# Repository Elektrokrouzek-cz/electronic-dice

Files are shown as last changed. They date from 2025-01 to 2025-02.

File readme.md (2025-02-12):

# Electronic dice
This is the construction of electronic dice for RedNetCon technological conference
workshop. It is based on NE555 timer and 4017 logical circuit. All components are 
in THT packages.

PCB is 2-layer and was designed using KiCad 8. Fabrication output for JLCPCB is in gerber folder.

Happy soldering!

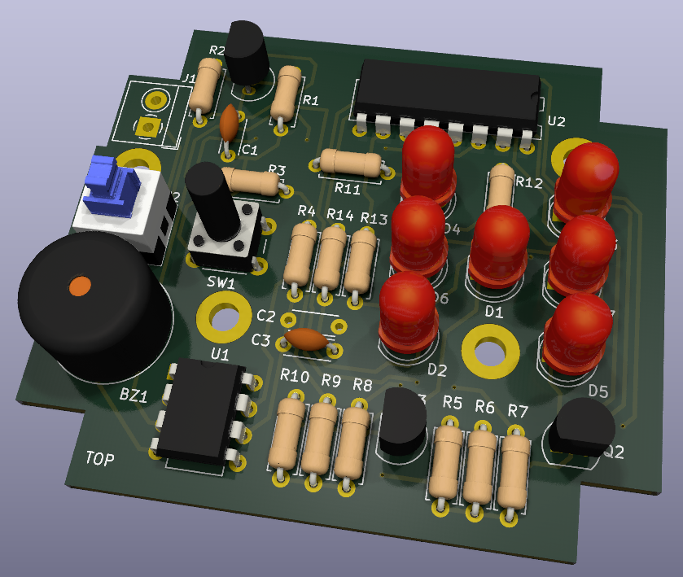
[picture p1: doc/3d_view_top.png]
3D view

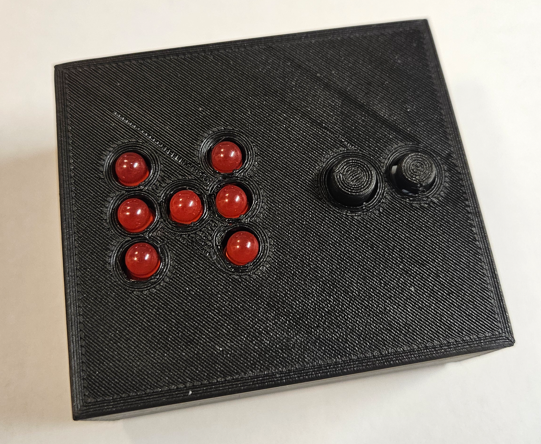
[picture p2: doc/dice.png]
Dice


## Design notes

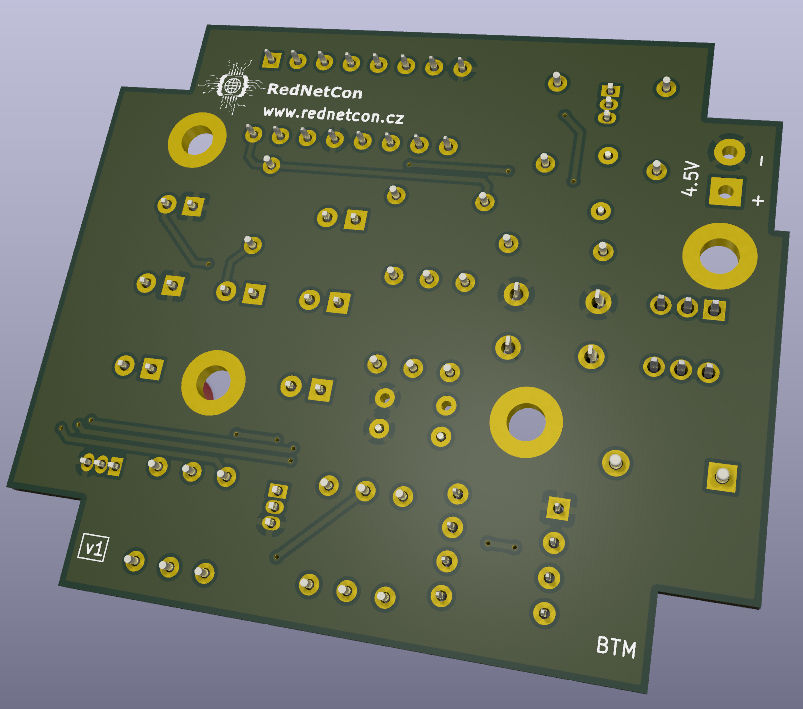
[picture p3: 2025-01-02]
doc/3d_view_btm.png

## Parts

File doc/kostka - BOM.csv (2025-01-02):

Reference | Value | Datasheet | Footprint | Qty | DNP
BZ1 | Buzzer | ~ | Buzzer_Beeper:Buzzer_12x9.5RM7.6 | 1
C1,C3 | 1uF | ~ | Capacitor_THT:C_Disc_D4.3mm_W1.9mm_P5.00mm | 2
C2 | 1uF | ~ | Capacitor_THT:C_Disc_D4.3mm_W1.9mm_P5.00mm | 1 | DNP
D1,D2,D3,D4,D5,D6,D7 | 5mm, R | ~ | LED_THT:LED_D5.0mm | 7
J1 | Screw_Terminal_01x02 | ~ | TerminalBlock_4Ucon:TerminalBlock_4Ucon_1x02_P3.50mm_Horizontal | 1
Q1 | BC556 | https://www.onsemi.com/pub/Collateral/BC556BTA-D.pdf | Package_TO_SOT_THT:TO-92_Inline | 1
Q2,Q3 | BC546 | https://www.onsemi.com/pub/Collateral/BC550-D.pdf | Package_TO_SOT_THT:TO-92_Inline | 2
R1,R2 | 1M | ~ | Resistor_THT:R_Axial_DIN0207_L6.3mm_D2.5mm_P7.62mm_Horizontal | 2
R3,R4,R5,R6,R7,R8,R9,R10 | 10k | ~ | Resistor_THT:R_Axial_DIN0207_L6.3mm_D2.5mm_P7.62mm_Horizontal | 8
R11,R13,R14 | 220R | ~ | Resistor_THT:R_Axial_DIN0207_L6.3mm_D2.5mm_P7.62mm_Horizontal | 3
R12 | 1k | ~ | Resistor_THT:R_Axial_DIN0207_L6.3mm_D2.5mm_P7.62mm_Horizontal | 1
SW1 | Push 6x6, H13mm | ~ | Button_Switch_THT:SW_PUSH_6mm_H13mm | 1
SW2 | DPDT 7x7mm, Turbo | ~ | Button_Switch_THT_Hap:SW_DPDT_7x7_Turbo | 1
U1 | NE555P | http://www.ti.com/lit/ds/symlink/ne555.pdf | Package_DIP:DIP-8_W7.62mm | 1
U2 | 4017 | http://www.intersil.com/content/dam/Intersil/documents/cd40/cd4017bms-22bms.pdf | Package_DIP:DIP-16_W7.62mm | 1

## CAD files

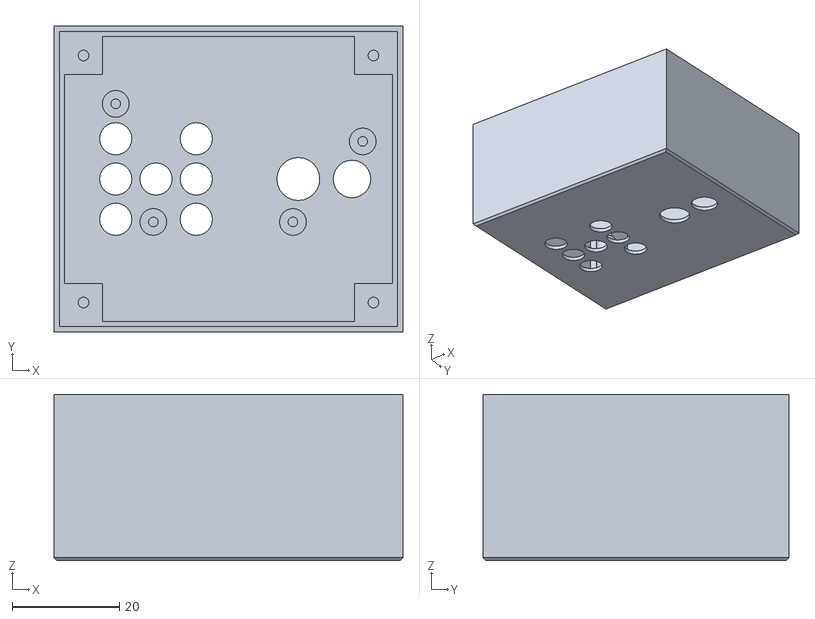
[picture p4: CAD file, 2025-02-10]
3d/dice_top.stl
65.0 x 57.0 x 31.0

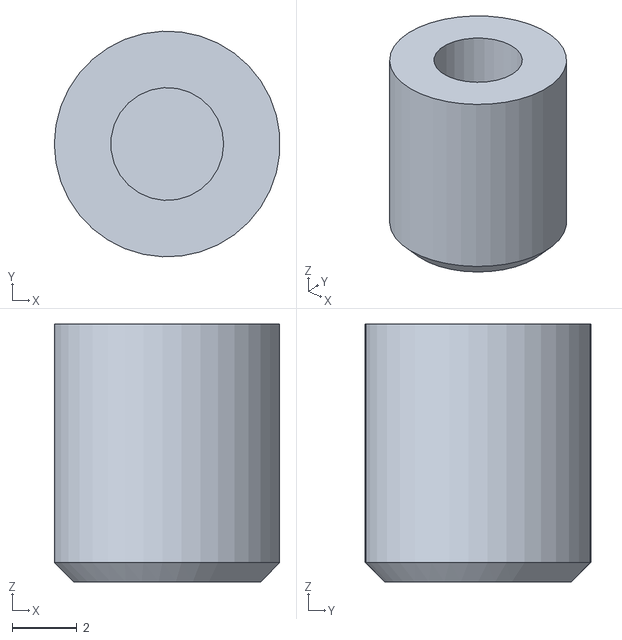
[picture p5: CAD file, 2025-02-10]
3d/dice_button_1.stl
6.99 x 6.99 x 8.00

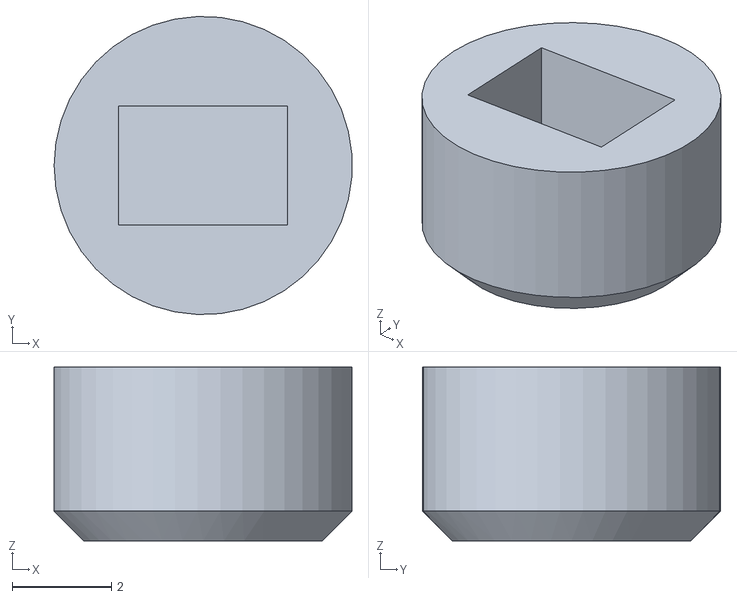
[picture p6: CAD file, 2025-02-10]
3d/dice_button_2.stl
5.99 x 6.00 x 3.50

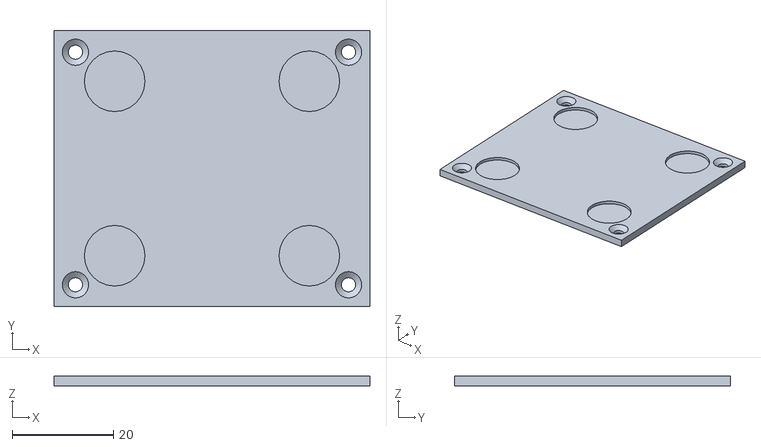
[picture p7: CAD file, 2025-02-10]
3d/dice_bottom.stl
62.5 x 54.5 x 2.00

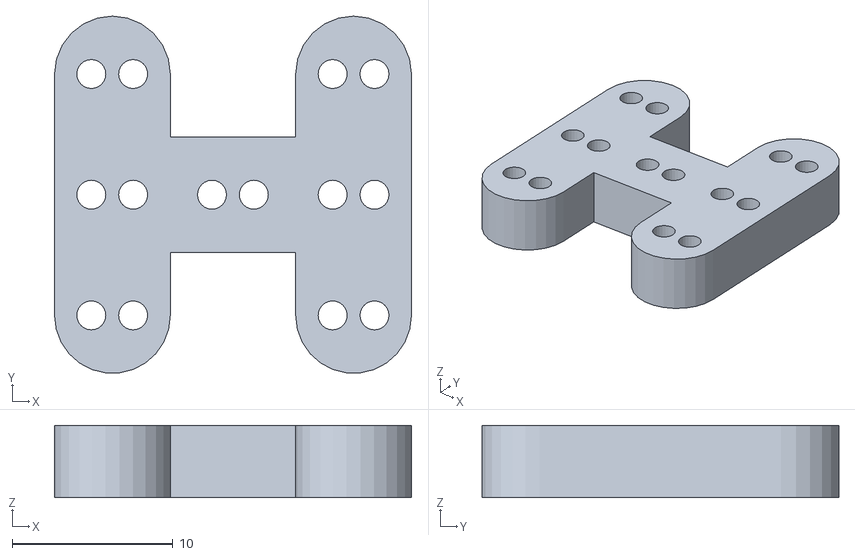
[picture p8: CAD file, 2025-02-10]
3d/dice_led_spacer.stl
22.2 x 22.2 x 4.50

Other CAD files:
3d/dice.f3d

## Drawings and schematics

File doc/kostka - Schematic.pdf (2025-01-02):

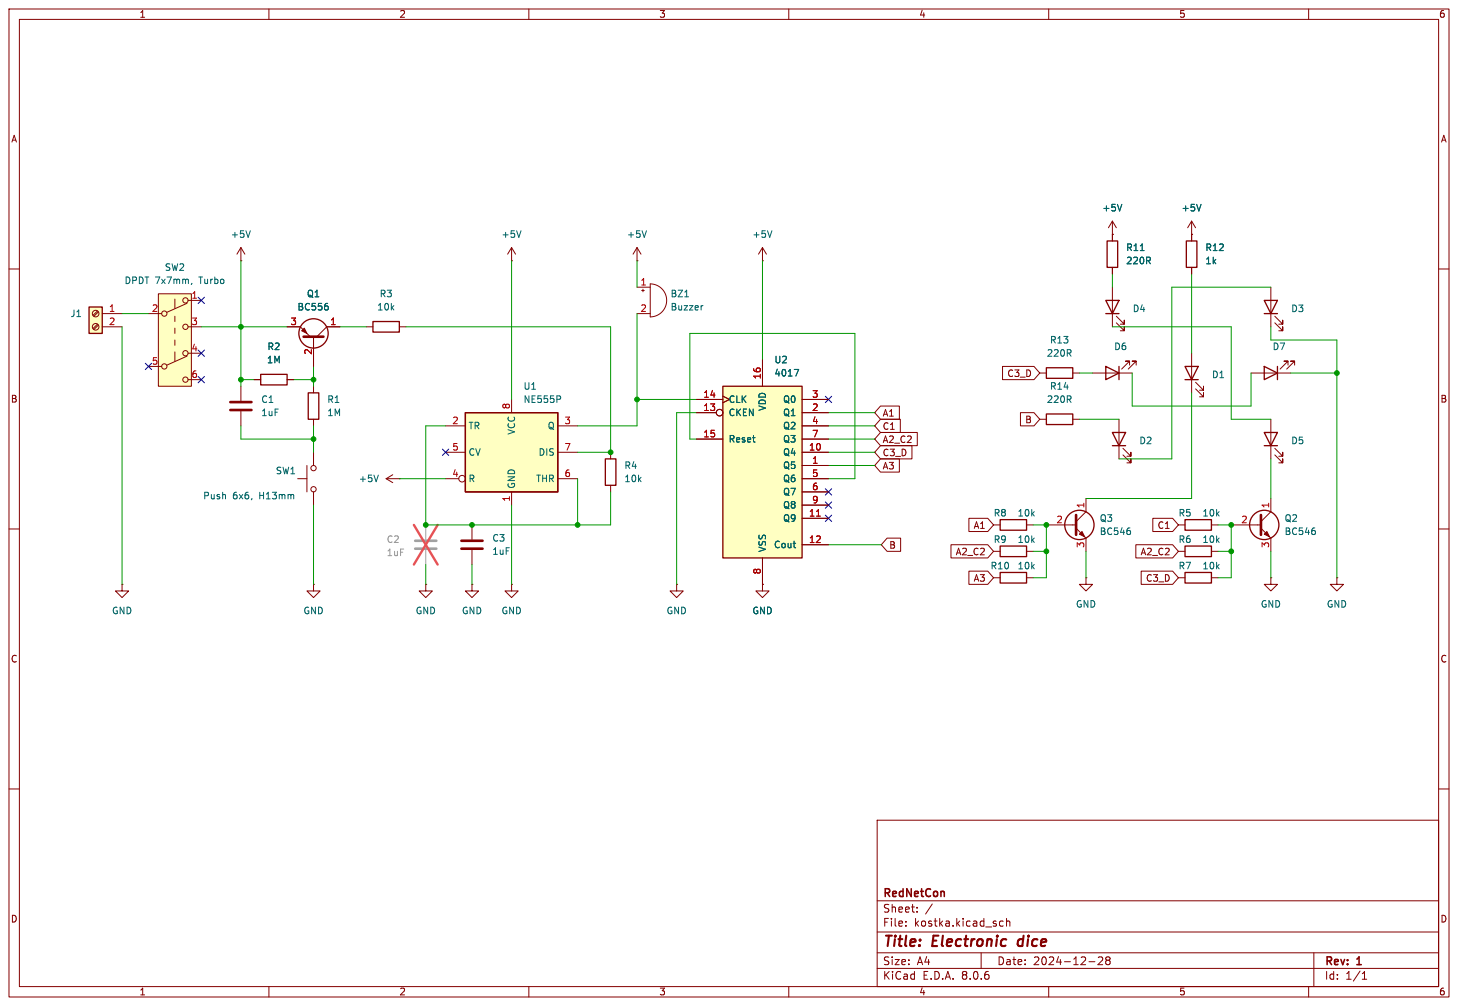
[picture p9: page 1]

File: kostka.kicad_sch Sheet: / RedNetCon

Id: 1/1 Title: Electronic dice

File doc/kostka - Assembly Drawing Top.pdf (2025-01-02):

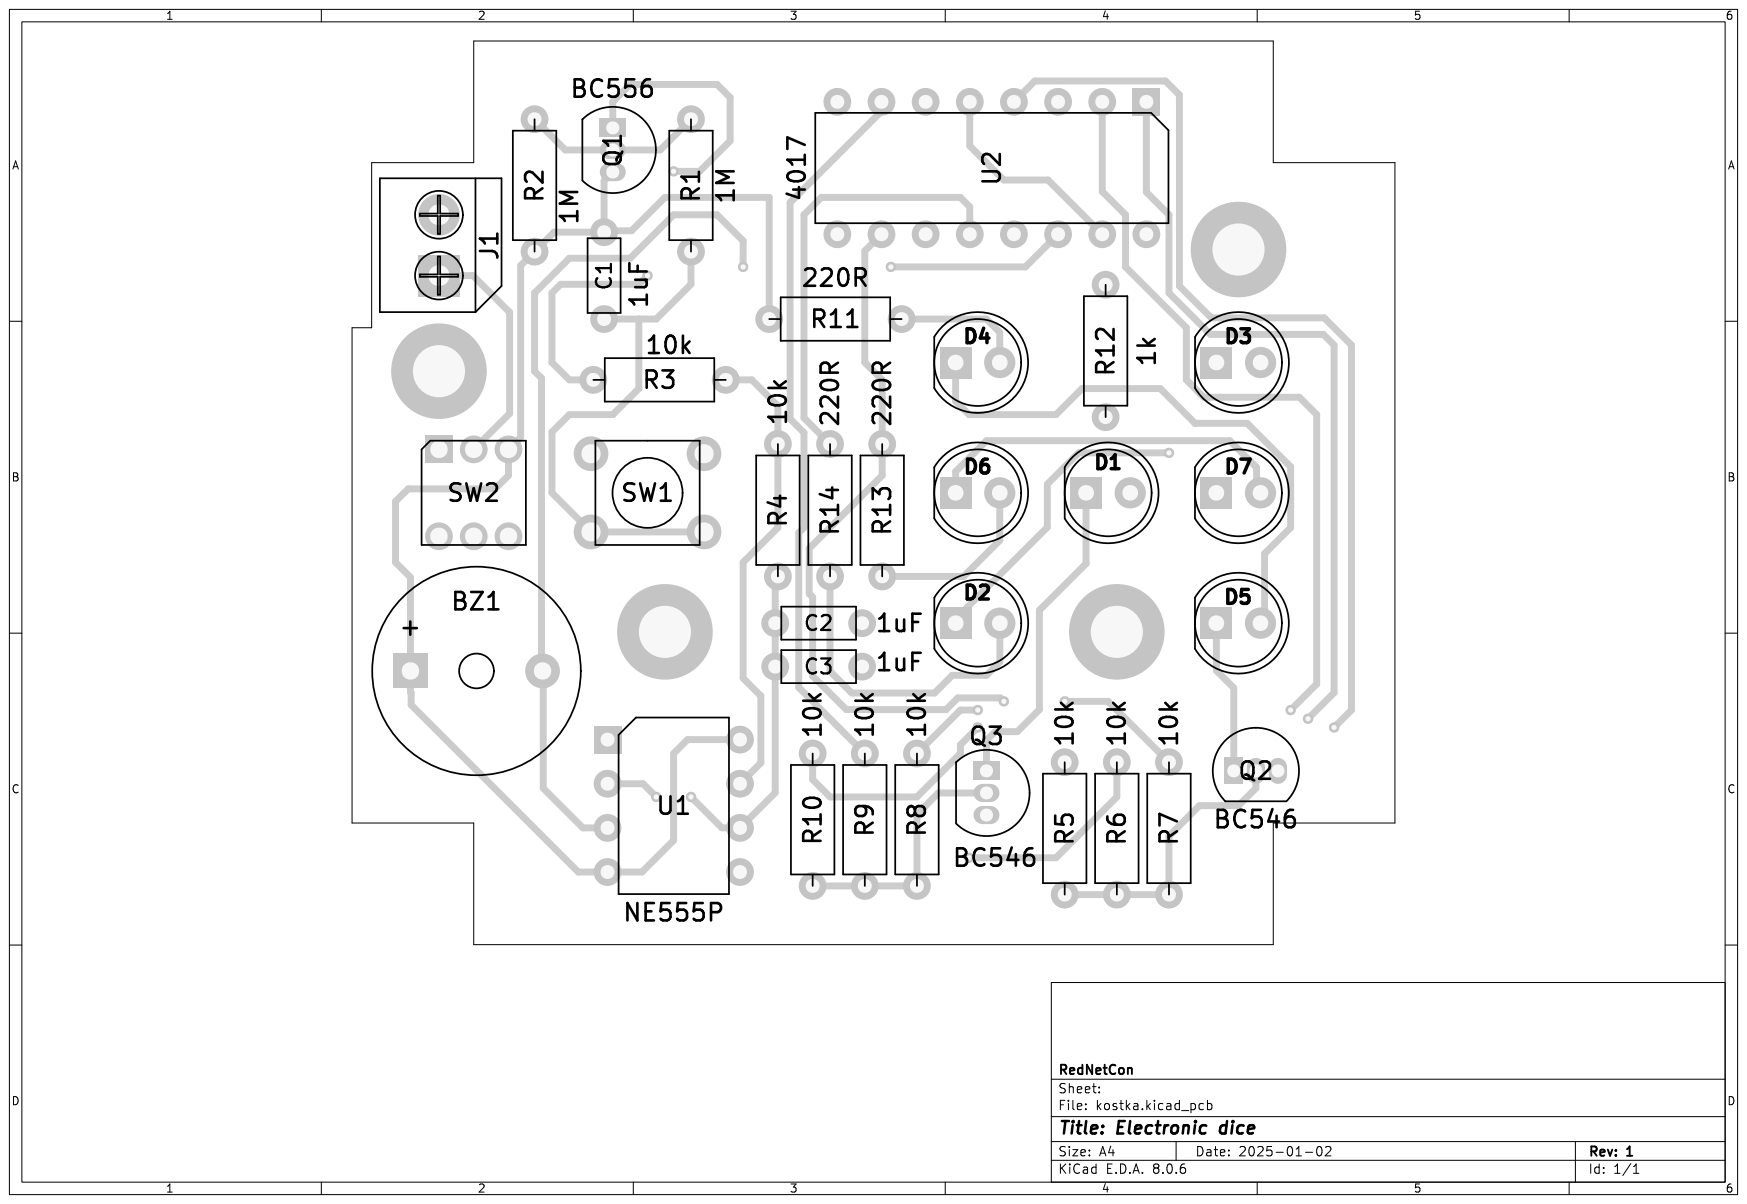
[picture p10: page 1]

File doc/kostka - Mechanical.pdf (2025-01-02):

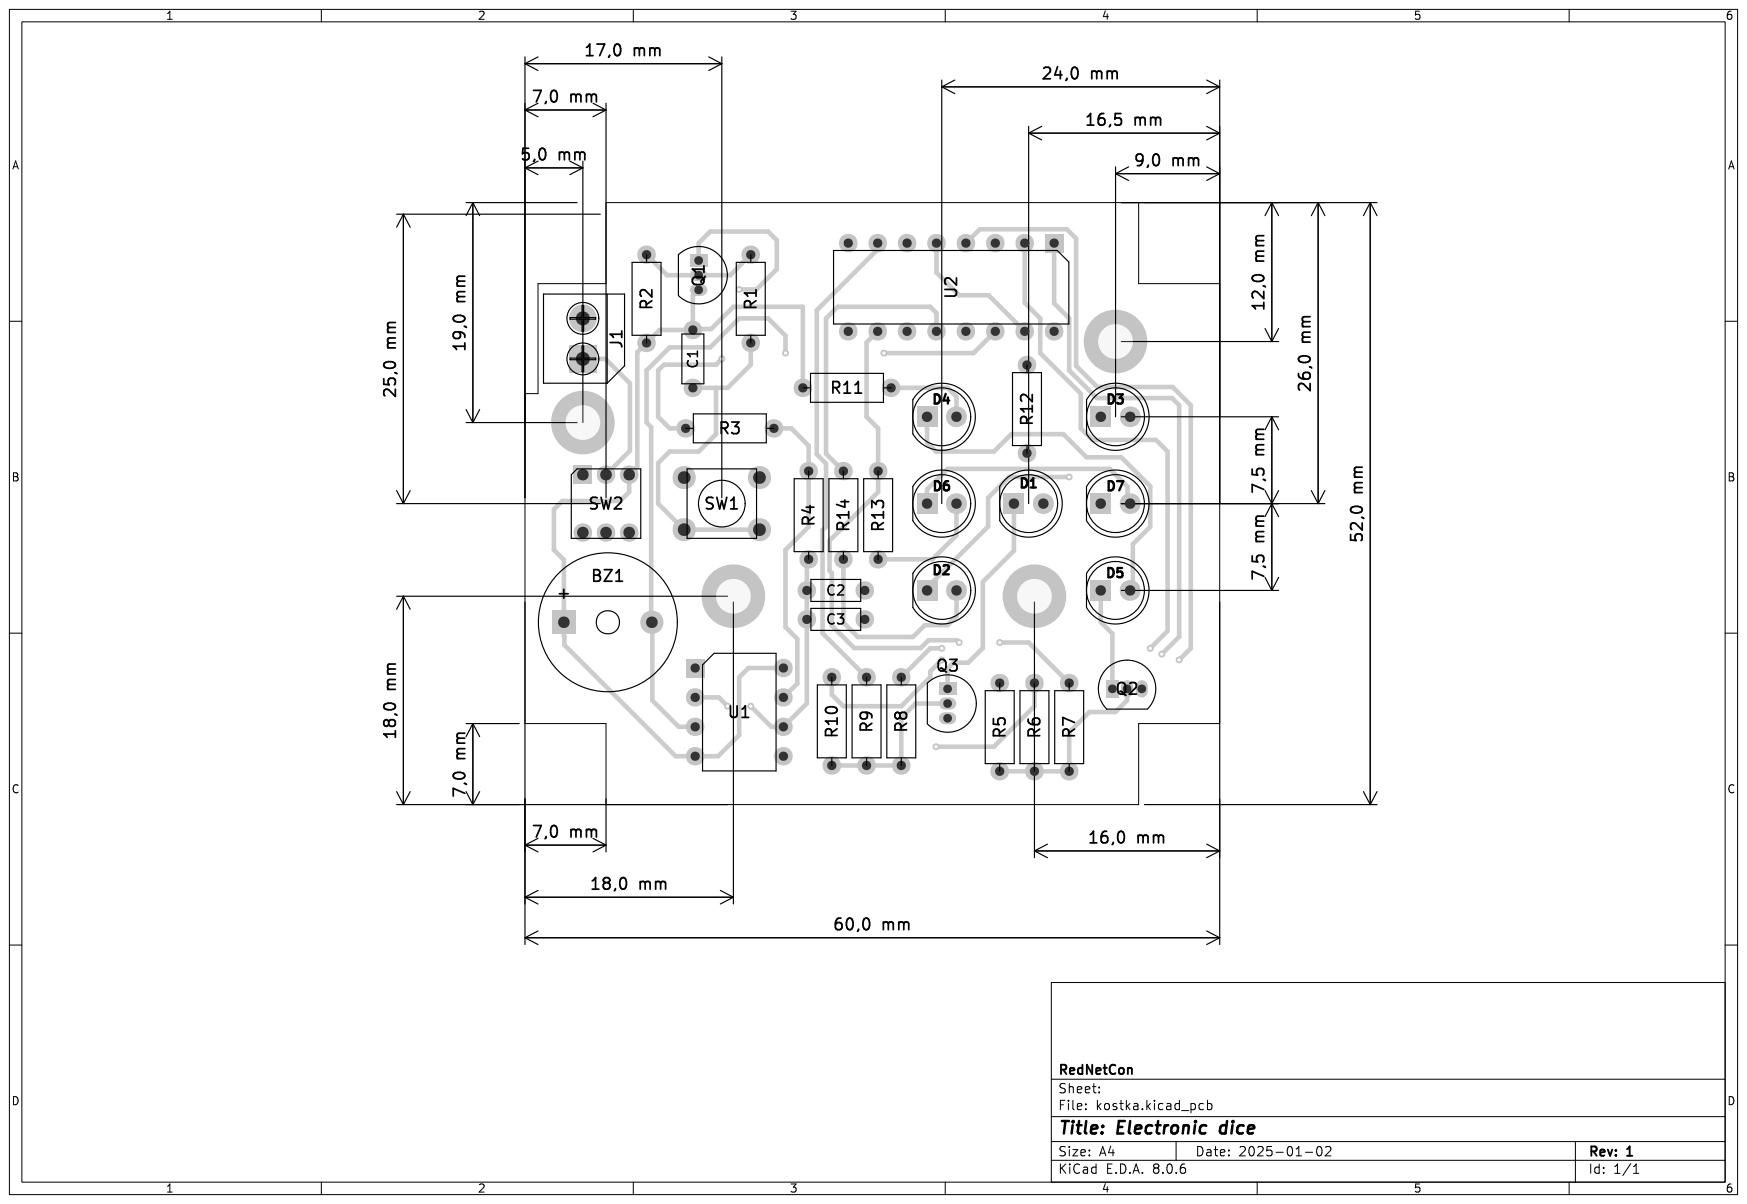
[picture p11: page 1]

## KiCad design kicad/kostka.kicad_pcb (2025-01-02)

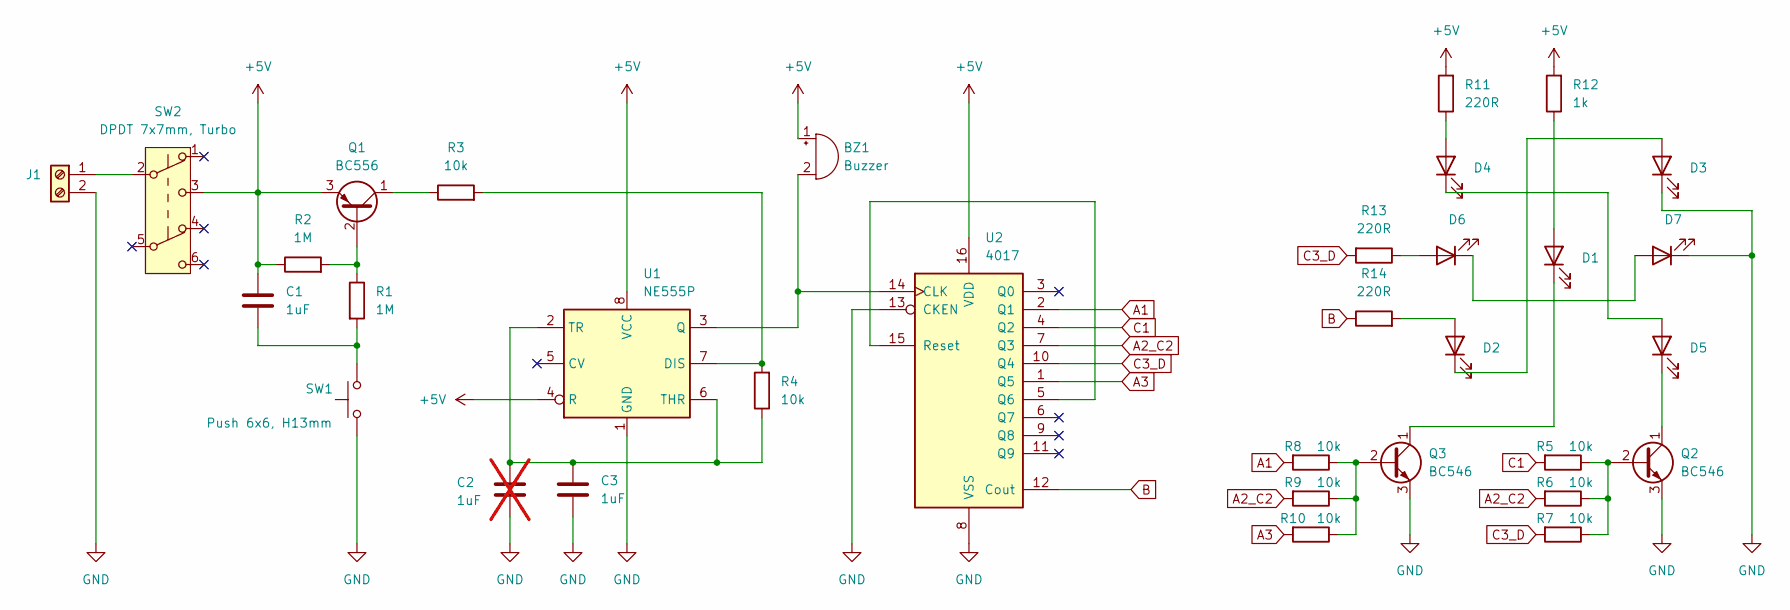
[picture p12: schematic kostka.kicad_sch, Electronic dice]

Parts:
BZ1: Buzzer; Buzzer_12x9.5RM7.6
C1, C3: 1uF; C_Disc_D4.3mm_W1.9mm_P5.00mm
C2: 1uF; C_Disc_D4.3mm_W1.9mm_P5.00mm; not fitted
D1, D2, D3, D4, D5, D6, D7: 5mm, R; LED_D5.0mm
J1: Screw_Terminal_01x02; TerminalBlock_4Ucon_1x02_P3.50mm_Horizontal
Q1: BC556; TO-92_Inline
Q2, Q3: BC546; TO-92_Inline
R1, R2: 1M; R_Axial_DIN0207_L6.3mm_D2.5mm_P7.62mm_Horizontal
R3, R4, R5, R6, R7, R8, R9, R10: 10k; R_Axial_DIN0207_L6.3mm_D2.5mm_P7.62mm_Horizontal
R11, R13, R14: 220R; R_Axial_DIN0207_L6.3mm_D2.5mm_P7.62mm_Horizontal
R12: 1k; R_Axial_DIN0207_L6.3mm_D2.5mm_P7.62mm_Horizontal
SW1: Push 6x6, H13mm; SW_PUSH_6mm_H13mm
SW2: DPDT 7x7mm, Turbo; SW_DPDT_7x7_Turbo
U1: NE555P; DIP-8_W7.62mm
U2: 4017; DIP-16_W7.62mm

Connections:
+5V: BZ1.1 (+), C1.1, Q1.3 (E), R2.1, R11.2, R12.2, SW2.3 (C), U1.4 (R), U1.8 (VCC), U2.16 (VDD)
A1: R8.2, U2.2 (Q1)
A2_C2: R6.2, R9.2, U2.7 (Q3)
A3: R10.2, U2.1 (Q5)
B: R14.1, U2.12 (Cout)
C1: R5.2, U2.4 (Q2)
C3_D: R7.2, R13.2, U2.10 (Q4)
GND: C2.2, C3.2, D3.1 (K), D7.1 (K), J1.2, Q2.3 (E), Q3.3 (E), SW1.1, U1.1 (GND), U2.8 (VSS), U2.13 (CKEN)
unnamed: BZ1.2 (-), U1.3 (Q), U2.14 (CLK)
unnamed: C1.2, R1.2, SW1.2
unnamed: D1.2 (A), R12.1
unnamed: D1.1 (K), Q3.1 (C)
unnamed: D2.2 (A), R14.2
unnamed: D2.1 (K), D3.2 (A)
unnamed: D4.2 (A), R11.1
unnamed: D4.1 (K), D5.2 (A)
unnamed: D5.1 (K), Q2.1 (C)
unnamed: D6.2 (A), R13.1
unnamed: D6.1 (K), D7.2 (A)
unnamed: J1.1, SW2.2 (B)
unnamed: Q1.2 (B), R1.1, R2.2
unnamed: Q1.1 (C), R3.1
unnamed: Q2.2 (B), R5.1, R6.1, R7.1
unnamed: Q3.2 (B), R8.1, R9.1, R10.1
unnamed: R3.2, R4.2, U1.7 (DIS)
unnamed: C2.1, C3.1, R4.1, U1.2 (TR), U1.6 (THR)
unnamed: U2.5 (Q6), U2.15 (Reset)

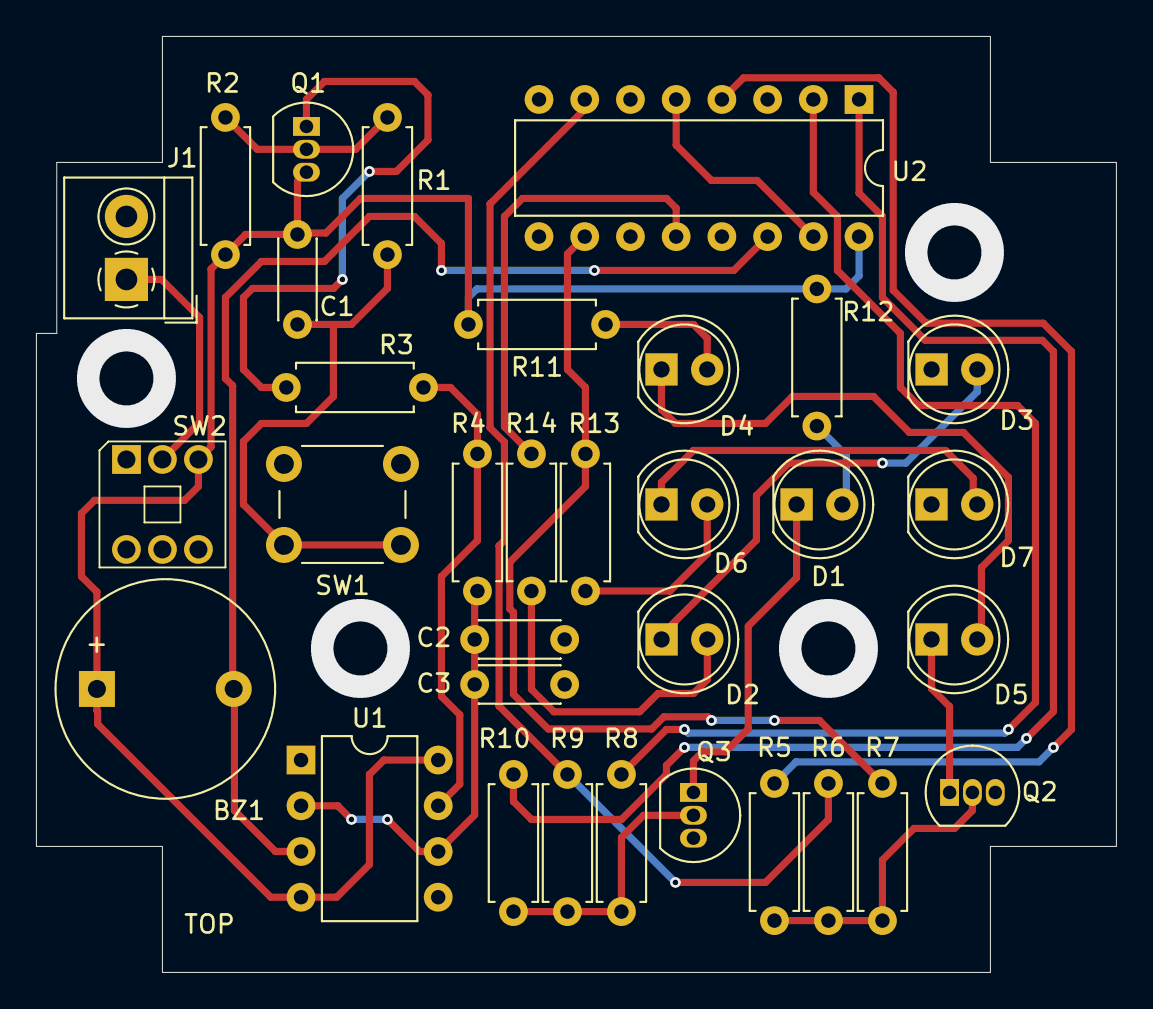
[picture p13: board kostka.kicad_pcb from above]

Board: 2 copper layers, 60.0 x 52.0 mm, 33 parts (0 on the bottom side), 27 nets.

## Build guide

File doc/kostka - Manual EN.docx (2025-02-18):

# Electronic dice

## Schematic description

Dice construction generates random numbers from 1 to 6 after the button is pressed. These numbers are shown using LED diodes in the same way as on classic dice. Transistor Q1 is opened by pressing the button. Capacitor C1 gets charged and U1 timer starts to generate fast pulses for the counter. Piezo buzzer beeps with each pulse. Capacitor C1 and resistors R2 and R1 keep Q1 open even if the button is released. However, the capacitor slowly discharges, and the transistor is closing. This causes U1 timer frequency decrease and stop after some time.

Johnson counter U2 takes care of drawing random numbers. Its output Q6 is connected to RESET input. This assures counting between number 1 to 6. Correct number display as on classic dice is achieved using transistors Q2 and Q3. They works as logical OR.

## Construction

Caution: Capacitor C2 is not populated.

We populate components by their height from the lowest to the highest. We start by resistors and continue by capacitors, sockets for integrated circuits, transistors, terminal and piezo buzzer. Then we populate LED diodes. There is a plastic spacer to assure correct placement and the same height.

Switch SW2 and button SW1 is populated last. Integrated circuits are placed into sockets.

## How to get it into service

It should work on the first try when everything was soldered well. Random number shall appear after power up. Then the number shall quickly change after button is pressed. Dice shall stop after some time.

## Bill of materials

Annotation | Value | Qty
BZ1 | Buzzer | 1
C1,C3 | 1uF | 2
~~C2~~ | ~~1uF~~ | ~~1~~
D1,D2,D3,D4,D5,D6,D7 | 5mm, R | 7
J1 | Screw_Terminal_01x02 | 1
Q1 | BC556 | 1
Q2,Q3 | BC546 | 2
R1,R2 | 1M | 2
R3,R4,R5,R6,R7,R8,R9,R10 | 10k | 8
R11,R13,R14 | 220R | 3
R12 | 1k | 1
SW1 | Push 6x6, H13mm | 1
SW2 | DPDT 7x7mm, Turbo | 1
U1 | NE555P | 1
U2 | 4017 | 1

## LED diodes

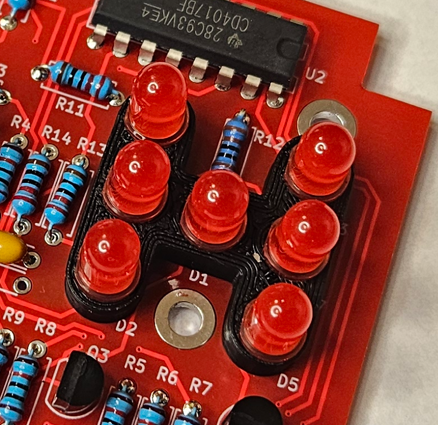
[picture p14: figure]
Obsah obrázku elektronika, obvod, Elektronické inženýrství, Obvodoví součástka Obsah vygenerovaný umělou inteligencí může být nesprávný.

## Switch

Switch orientation is important. Populate it as shown in the photo.

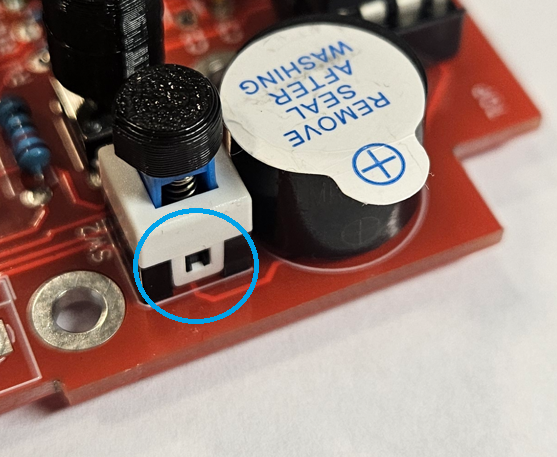
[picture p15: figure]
Obsah obrázku elektronika, Obvodoví součástka, Elektronické inženýrství, Pasivní součástka Obsah vygenerovaný umělou inteligencí může být nesprávný.

## Mechanical assembly

Battery holder should be glued to the bottom box part using double sided tape. It should be centered as well as possible.

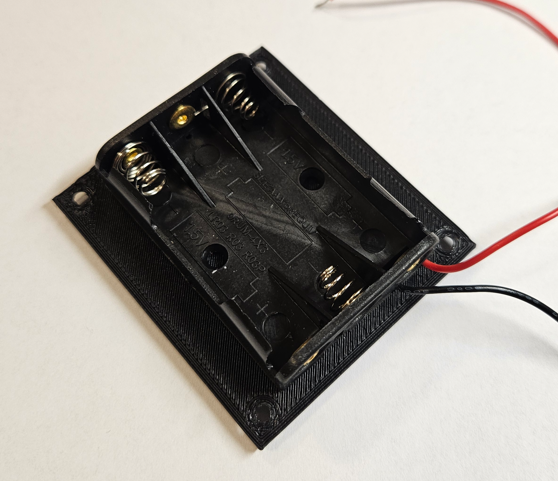
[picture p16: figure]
Obsah obrázku elektronika, kabel, Elektronické inženýrství, Elektrické vedení Obsah vygenerovaný umělou inteligencí může být nesprávný.

Then PCB should be fastened using smaller screws to the top box part.

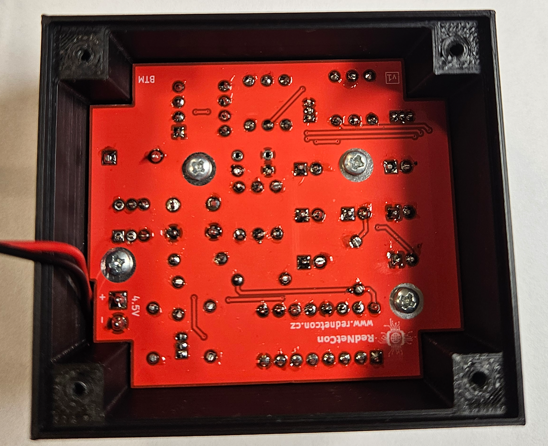
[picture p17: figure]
Obsah obrázku elektronika, Elektronické inženýrství, text, Elektronické zařízení Obsah vygenerovaný umělou inteligencí může být nesprávný.

Place batteries to the battery holder and fasten bottom box part to the top using bigger screws. Plastic legs should be glued.

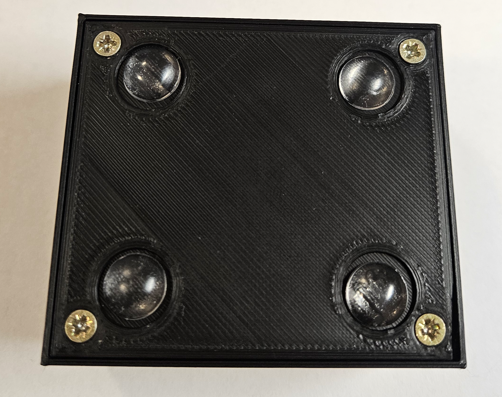
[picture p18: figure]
Obsah obrázku kruh, elektronika Obsah vygenerovaný umělou inteligencí může být nesprávný.

## PCB assembly

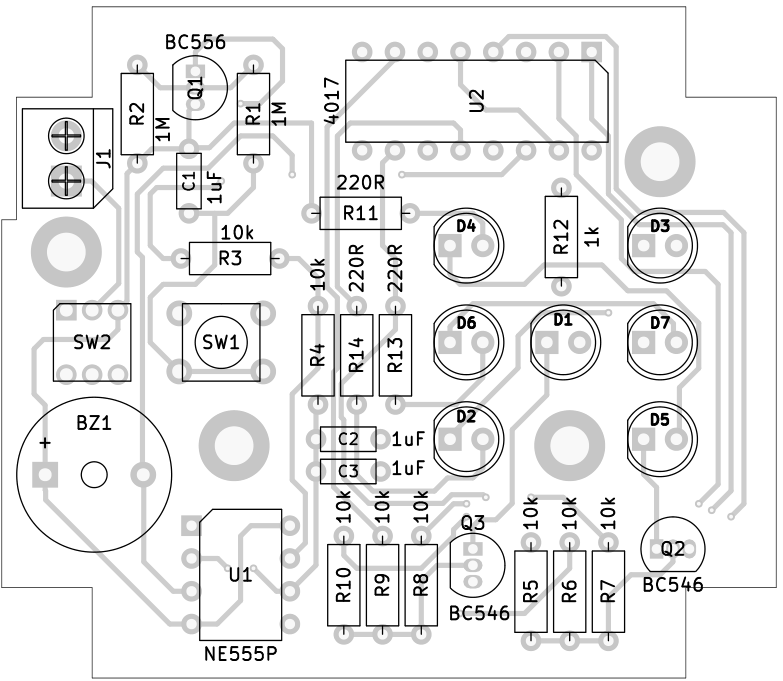
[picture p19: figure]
Obsah obrázku text, diagram, Plán, skica Obsah vygenerovaný umělou inteligencí může být nesprávný.

## Schematic

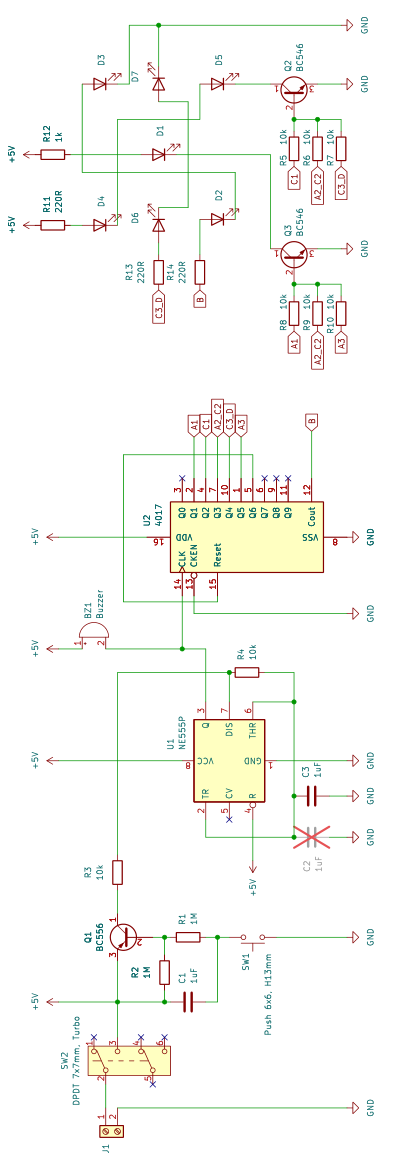
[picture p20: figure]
Obsah obrázku diagram, Plán, řada/pruh, schématické Obsah vygenerovaný umělou inteligencí může být nesprávný.

www.rednetcon.cz

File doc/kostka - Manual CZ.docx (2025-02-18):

# Elektronická hrací kostka

## Popis zapojení

Konstrukce elektronické hrací kostky náhodně losuje číslo 1 až 6 po stisknutí tlačítka a zobrazí je pomocí LED diod stejně, jako je to na klasické hrací kostce. Stisknutím tlačítka se otevře tranzistor Q1, nabije se kondenzátor C1 a časovač U1 začne rychle generovat pulzy pro čítač. Zároveň s každým pulzem pípne piezo měnič. Kondenzátor C1 a rezistory R2 a R1 drží tranzistor Q1 otevřen i po uvolnění tlačítka. Kondenzátor však se postupně vybíjí a tranzistor se přivírá. Tím dochází ke snižování výstupní frekvence časovače U1 až se úplně zastaví.

O losování čísel se stará Johnsonův čítač U2, jehož výstup Q6 je zapojen do RESET vstupu. Tím je zaručeno losování od 1 do 6. Správného zobrazení, jako na klasické kostce pomocí LED diod, je docíleno pomocí tranzistorů Q2 a Q3, které zde fungují jako logický OR.

## Popis sestavení

Upozornění: Kondenzátor C2 se neosazuje.

Osazujeme součástky od nejnižších po nejvyšší. Začneme rezistory, pokračujeme kondenzátory, paticemi pro integrované obvody, tranzistory, svorkovnicí, a piezem. Pokračujeme osazením LED diod. Aby se nám dobře pracovalo a LED diody byly pěkně srovnané ve stejné výšce, je stavebnice vybavena plastovou podložkou.

Nakonec osadíme spínač SW2 a tlačítko SW1. Integrované obvody vložíme do patic.

## Oživení

Pokud jste pracovali pečlivě mělo by zapojení fungovat na první pokus. Po zapnutí by se mělo zobrazit náhodné číslo. Stisknutím tlačítka začne kostka losovat a postupně se zastaví na náhodně vylosovaném čísle.

## Seznam součástek

Označení | Hodnota | Počet
BZ1 | Buzzer | 1
C1,C3 | 1uF | 2
~~C2~~ | ~~1uF~~ | ~~1~~
D1,D2,D3,D4,D5,D6,D7 | 5mm, R | 7
J1 | Screw_Terminal_01x02 | 1
Q1 | BC556 | 1
Q2,Q3 | BC546 | 2
R1,R2 | 1M | 2
R3,R4,R5,R6,R7,R8,R9,R10 | 10k | 8
R11,R13,R14 | 220R | 3
R12 | 1k | 1
SW1 | Push 6x6, H13mm | 1
SW2 | DPDT 7x7mm, Turbo | 1
U1 | NE555P | 1
U2 | 4017 | 1

## Osazení LED diod

Obsah obrázku elektronika, obvod, Elektronické inženýrství, Obvodoví součástka Obsah vygenerovaný umělou inteligencí může být nesprávný.

## Osazení vypínače

Orientace vypínače je důležitá. Osaďte dle obrázku.

Obsah obrázku elektronika, Obvodoví součástka, Elektronické inženýrství, Pasivní součástka Obsah vygenerovaný umělou inteligencí může být nesprávný.

## Mechanické sestavení

Držák baterií přilepíme na spodní část krabičky pomocí oboustranné lepicí pásky. Snažíme se jej přilepit doprostřed.

Obsah obrázku elektronika, kabel, Elektronické inženýrství, Elektrické vedení Obsah vygenerovaný umělou inteligencí může být nesprávný.

Plošný spoj upevníme do horní části krabičky pomocí menších šroubků.

Obsah obrázku elektronika, Elektronické inženýrství, text, Elektronické zařízení Obsah vygenerovaný umělou inteligencí může být nesprávný.

Vložíme baterie a spodní část krabičky přišroubujeme do části horní pomocí větších šroubků. Nakonec přilepíme gumové nožičky.

Obsah obrázku kruh, elektronika Obsah vygenerovaný umělou inteligencí může být nesprávný.

## Osazovací výkres

Obsah obrázku text, diagram, Plán, skica Obsah vygenerovaný umělou inteligencí může být nesprávný.

## Schéma zapojení

Obsah obrázku diagram, Plán, řada/pruh, schématické Obsah vygenerovaný umělou inteligencí může být nesprávný.

www.rednetcon.cz

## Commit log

2025-01-20 Housing 3D model
    [dice.f3d, dice_bottom.obj, dice_button_1.obj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]
2025-02-10 3D models updated
    [dice.f3d, dice_bottom.obj, dice_bottom.stl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]
